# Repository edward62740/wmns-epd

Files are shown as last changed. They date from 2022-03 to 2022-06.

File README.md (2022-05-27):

# WMNS-EPD
Simple Wi-Fi/BLE enabled e-paper display. Designed for displaying real-time sensor data. Extention of [WMNS](https://github.com/edward62740/Wireless-Mesh-Network-System).</br></br>




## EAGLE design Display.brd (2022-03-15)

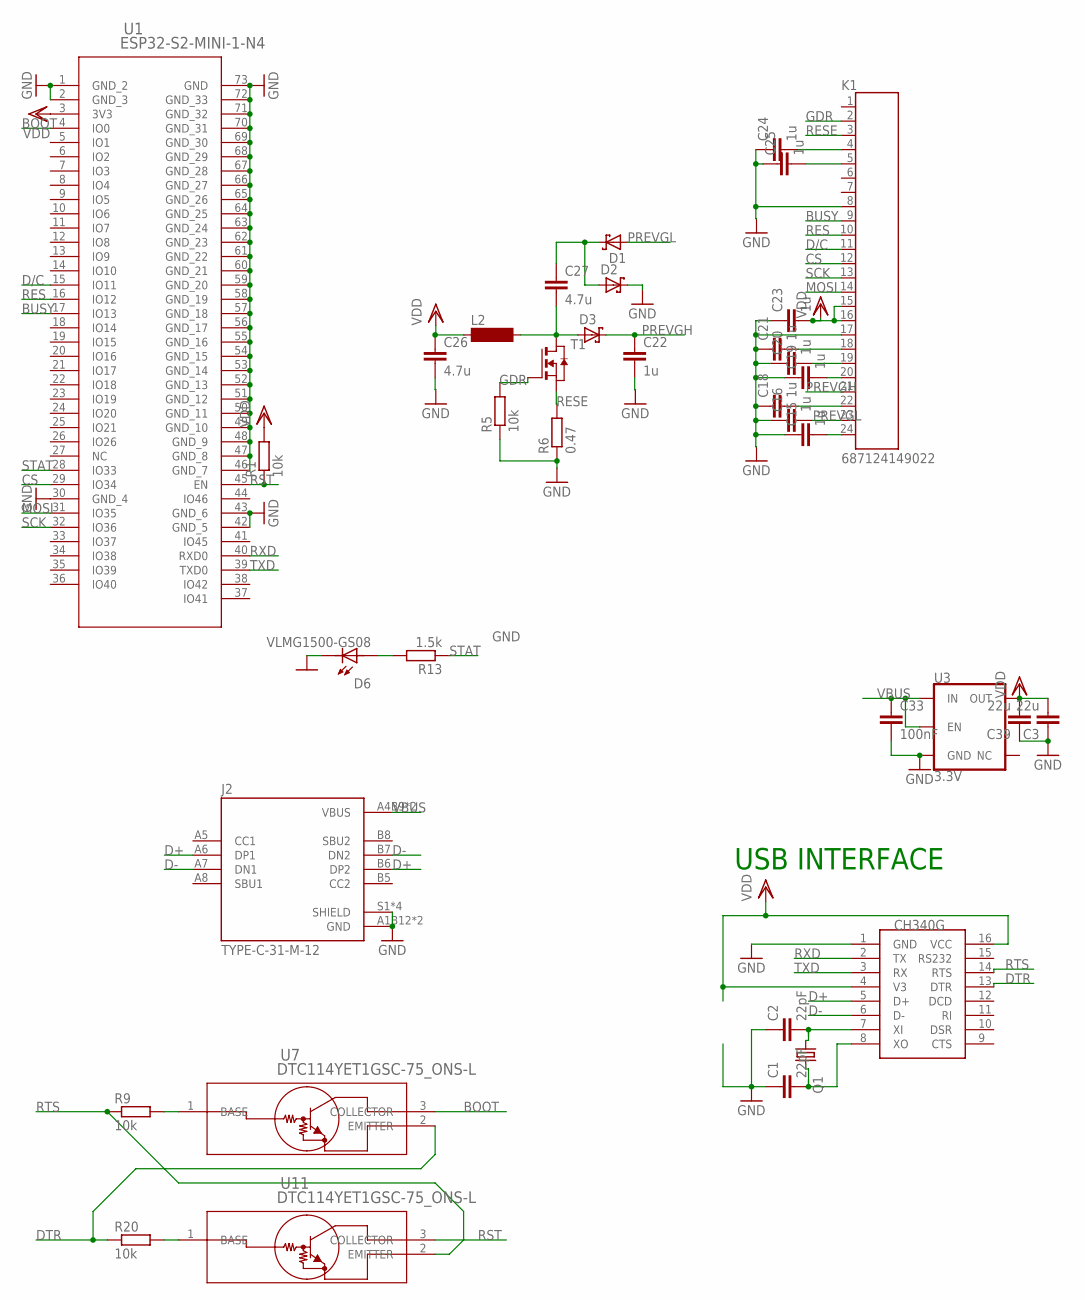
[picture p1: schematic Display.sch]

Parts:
C1, C2: 22pF; C0402
C3, C39: 22u; C0603R
C15, C16, C18, C19, C20, C21, C22, C23, C24, C25: 1u; C0402
C26, C27: 4.7u; C0402
C33: 100nF; C0402
D1, D2, D3: 1PS79SB30,115; SOD523
D6: VLMG1500-GS08; LEDC1005X35N
J2: TYPE-C-31-M-12; HRO_TYPE-C-31-M-12
K1: 687124149022
L2: SM-NE29
Q1: KX-7; 3.2X2.5_KX-7
R1, R5, R9, R20: 10k; R0402
R6: 0.47; R0402
R13: 1.5k; R0402
T1: NMOSSOT23; SOT-23
U1: ESP32-S2-MINI-1-N4; ESP32-S2-MINI-1-N4_EXP
U3: 3.3V; SOT23-5
U5: H; SOIC16
U7, U11: DTC114YET1GSC-75_ONS-L; SC-75_ONS-L

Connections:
BOOT: U1.4 (IO0), U7.3 (COLLECTOR)
BUSY: K1.9, U1.17 (IO13)
CS: K1.12, U1.29 (IO34)
D+: J2.A6 (DP1), J2.B6 (DP2), U5.5 (D+)
D-: J2.A7 (DN1), J2.B7 (DN2), U5.6 (D-)
D/C: K1.11, U1.15 (IO11)
DTR: R20.1, U5.13 (DTR), U7.2 (EMITTER)
GDR: K1.2, R5.2, T1.3 (G)
GND: C1.1, C2.1, C3.1, C15.1, C16.1, C18.1, C19.1, C20.1, C21.1, C22.2, C23.1, C24.1, C25.1, C26.2, C33.2, C39.1, D2.1 (K), D6.2, J2.A1B12 (GND), J2.B1A12 (GND), J2.S1 (SHIELD), J2.S2 (SHIELD), J2.S3 (SHIELD), J2.S4 (SHIELD), K1.8, K1.17, R5.1, R6.1, U1.1 (GND_2), U1.2 (GND_3), U1.30 (GND_4), U1.42 (GND_5), U1.43 (GND_6), U1.46 (GND_7), U1.47 (GND_8), U1.48 (GND_9), U1.49 (GND_10), U1.50 (GND_11), U1.51 (GND_12), U1.52 (GND_13), U1.53 (GND_14), U1.54 (GND_15), U1.55 (GND_16), U1.56 (GND_17), U1.57 (GND_18), U1.58 (GND_19), U1.59 (GND_20), U1.60 (GND_21), U1.61 (GND_22), U1.62 (GND_23), U1.63 (GND_24), U1.64 (GND_25), U1.65 (GND_26), U1.66 (GND_27), U1.67 (GND_28), U1.68 (GND_29), U1.69 (GND_30), U1.70 (GND_31), U1.71 (GND_32), U1.72 (GND_33), U1.73 (GND), U3.2 (GND), U5.1 (GND)
MOSI: K1.14, U1.31 (IO35)
unnamed: C1.2, Q1.3 (2), U5.8 (XO)
unnamed: C27.2, D3.2 (A), L2.2, T1.1 (D)
unnamed: C21.2, K1.18
unnamed: C2.2, Q1.1, U5.7 (XI)
unnamed: C18.2, K1.22
unnamed: C20.2, K1.19
unnamed: C19.2, K1.20
unnamed: C15.2, K1.24
unnamed: C24.2, K1.4
unnamed: C25.2, K1.5
unnamed: C27.1, D1.1 (K), D2.2 (A)
unnamed: D6.1, R13.2
unnamed: R20.2, U11.1 (BASE)
unnamed: R9.2, U7.1 (BASE)
PREVGH: C22.1, D3.1 (K), K1.21
PREVGL: C16.2, D1.2 (A), K1.23
RES: K1.10, U1.16 (IO12)
RESE: K1.3, R6.2, T1.2 (S)
RST: R1.1, U1.45 (EN), U11.3 (COLLECTOR)
RTS: R9.1, U5.14 (RTS), U11.2 (EMITTER)
RXD: U1.40 (RXD0), U5.2 (TX)
SCK: K1.13, U1.32 (IO36)
STAT: R13.1, U1.28 (IO33)
TXD: U1.39 (TXD0), U5.3 (RX)
VBUS: C33.1, J2.A4B9 (VBUS), J2.B4A9 (VBUS), U3.1 (IN), U3.3 (EN)
VDD: C3.2, C23.2, C26.1, C39.2, K1.15, K1.16, L2.1, R1.2, U1.3 (3V3), U3.5 (OUT), U5.4 (V3), U5.16 (VCC)

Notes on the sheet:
USB INTERFACE

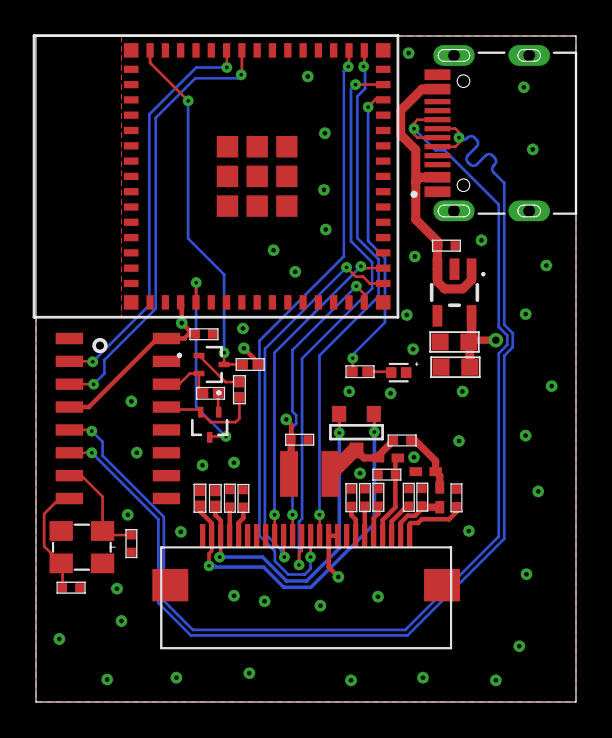
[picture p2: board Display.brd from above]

Board: 4 copper layers, 30.0 x 37.0 mm, 37 parts (0 on the bottom side), 36 nets.

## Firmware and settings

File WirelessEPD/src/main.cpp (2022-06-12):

#include <Arduino.h>
#include <GxEPD2_BW.h> // including both doesn't use more code or ram
#include <GxEPD2_3C.h> // including both doesn't use more code or ram
#include <Fonts/FreeMonoBold18pt7b.h>
#include <Fonts/FreeSansBold24pt7b.h>
#include <Fonts/FreeSansBold18pt7b.h>
#include <Fonts/FreeSansBold12pt7b.h>
#include <Fonts/FreeSansBold9pt7b.h>
#include <Fonts/FreeSans9pt7b.h>
#include <InfluxDbClient.h>
#include <InfluxDbCloud.h>

/* InfluxDB Connection Parameters */
#define WIFI_SSID ""
#define WIFI_PASSWORD ""
#define INFLUXDB_URL ""
// InfluxDB v2 server or cloud API authentication token (Use: InfluxDB UI -> Data -> Tokens -> <select token>)
#define INFLUXDB_TOKEN ""
// InfluxDB v2 organization id (Use: InfluxDB UI -> User -> About -> Common Ids )
#define INFLUXDB_ORG ""
// InfluxDB v2 bucket name (Use: InfluxDB UI ->  Data -> Buckets)
#define INFLUXDB_BUCKET ""
#define TZ_INFO ""
#include <esp_task_wdt.h>
InfluxDBClient client(INFLUXDB_URL, INFLUXDB_ORG, INFLUXDB_BUCKET, INFLUXDB_TOKEN, InfluxDbCloud2CACert);
unsigned long previousMillis = 0;
uint32_t co2_hist[25] = {0, 0, 0, 0, 0, 0, 0, 0, 0, 0, 0, 0, 0, 0, 0, 0, 0, 0, 0, 0, 0, 0, 0, 0, 0};
uint32_t co2_max = 0;
uint32_t co2_min = 0;
GxEPD2_3C<GxEPD2_154_Z90c, GxEPD2_154_Z90c::HEIGHT> display(GxEPD2_154_Z90c(/*CS=D8*/ SS, /*DC=D3*/ 11, /*RST=D4*/ 12, /*BUSY=D2*/ 13));
bool boot = true;
void setup()
{

    pinMode(33, OUTPUT);
    Serial.begin(115200);
    WiFi.mode(WIFI_STA);

    WiFi.begin(WIFI_SSID, WIFI_PASSWORD);
    while (WiFi.status() != WL_CONNECTED)
    {
        Serial.println(WiFi.status());
        delay(2500);
    }

    client.setHTTPOptions(HTTPOptions().httpReadTimeout(200));
    client.setHTTPOptions(HTTPOptions().connectionReuse(true));
    // Check server connection
    if (client.validateConnection())
    {
        Serial.print("Connected to InfluxDB: ");
        Serial.println(client.getServerUrl());
    }
    else
    {
        Serial.print("InfluxDB connection failed: ");
        Serial.println(client.getLastErrorMessage());
    }
    Serial.println("[INIT] IFDB CONNECTION OK");
}
void loop()
{
    esp_task_wdt_init(15, true);

    display.init();
    display.setRotation(1);
    for (uint8_t i = 0; i < 25; i++)
    {
        co2_hist[i] = 500;
        co2_max = 500;
    }

    while (1)
    {
        if (WiFi.status() != WL_CONNECTED)
        {
            WiFi.disconnect();
            WiFi.begin(WIFI_SSID, WIFI_PASSWORD);
            vTaskDelay(2000);
        }
        unsigned long currentMillis = millis();
        if ((currentMillis - previousMillis >= 300000) || boot)
        {
            display.fillScreen(GxEPD_BLACK);
            previousMillis = currentMillis;
            String query = "from(bucket: \"MESH\") |> range(start: -1h) |> filter(fn: (r) => r._measurement == \"CO2\") |> filter(fn: (r) => r.UID == \"22016\") |> filter(fn: (r) => r._field == \"CO2\") |> last()";
            FluxQueryResult result = client.query(query);
            uint32_t co2 = 1;
            while (result.next())
            {
                co2 = (uint32_t)result.getValueByName("_value").getDouble();
            }
            display.setFont(&FreeSansBold24pt7b);
            display.setTextColor(GxEPD_WHITE);
            display.setCursor(1, 38);
            display.print(co2);
            int16_t ulx, uly;
            uint16_t w, h;
            display.getTextBounds((String)co2, 1, 40, &ulx, &uly, &w, &h);
            display.setTextColor(GxEPD_WHITE);
            display.setFont(&FreeSansBold12pt7b);

            display.setTextSize(1);
            display.setCursor(ulx + w + 3, 40);
            display.print("PPM");
            display.setCursor(ulx + w + 3, 20);
            display.setTextColor(GxEPD_RED);
            display.print("CO2");
            display.setTextColor(GxEPD_WHITE);
            digitalWrite(33, !digitalRead(33));
            co2_max = 1;
            co2_min = 9999;
            for (uint8_t i = 1; i < 25; i++)
            {

                memmove(&co2_hist[i - 1], &co2_hist[i], sizeof(uint32_t));
                Serial.print(co2_hist[i - 1]);
                Serial.print(" ");
                if (co2_hist[i] > co2_max)
                    co2_max = co2_hist[i];
                if ((co2_hist[i] < co2_min) && co2_hist[i] != 0)
                    co2_min = co2_hist[i];
            }
            if ((uint32_t)co2 > co2_max)
                co2_max = (uint32_t)co2;
            if (((uint32_t)co2 < co2_min) && (uint32_t)co2 != 0)
                co2_min = (uint32_t)co2;
            co2_hist[24] = (uint32_t)co2;
            display.getTextBounds("CO2", ulx + w + 5, 20, &ulx, &uly, &w, &h);
            display.setCursor(ulx + w + 2, 18);
            display.setFont(&FreeSansBold9pt7b);
            display.print(co2_max);
            display.setCursor(ulx + w + 2, 38);
            display.setFont(&FreeSansBold9pt7b);
            display.print(co2_min);
            for (uint8_t i = 0; i < 24; i++)
            {
                float hy = (50.00 / ((float)co2_max - (float)co2_min)) * ((float)co2_hist[i] - (float)co2_min);
                float ly = 0;
                float l2y = 0;
                float l3y = 0;
                float l4y = 0;
                float diff = 0;
                if (i != 24)
                {
                    diff = (float)co2_hist[i + 1] - (float)co2_hist[i];
                    ly = (50.00 / ((float)co2_max - (float)co2_min)) * (((float)co2_hist[i] - (float)co2_min) + (diff * 0.15));
                    l2y = (50.00 / ((float)co2_max - (float)co2_min)) * (((float)co2_hist[i] - (float)co2_min) + (diff * 0.50));
                    l3y = (50.00 / ((float)co2_max - (float)co2_min)) * (((float)co2_hist[i] - (float)co2_min) + (diff * 0.85));
                    l4y = (50.00 / ((float)co2_max - (float)co2_min)) * (((float)co2_hist[i] - (float)co2_min) + (diff));

                    Serial.println(" ");
                    Serial.print(ly);
                    Serial.print(" ");
                    Serial.print(l2y);
                    Serial.print(" ");
                    Serial.print(l3y);
                    Serial.print(" ");
                    Serial.print(l4y);
                    Serial.print(" ");
                    Serial.print(diff);

                    display.drawLine(0 + i * 8, 100 - hy, 2 + i * 8, 100 - ly, GxEPD_WHITE);
                    display.drawLine(2 + i * 8, 100 - ly, 4 + i * 8, 100 - l2y, GxEPD_WHITE);
                    display.drawLine(4 + i * 8, 100 - l2y, 6 + i * 8, 100 - l3y, GxEPD_WHITE);
                    display.drawLine(6 + i * 8, 100 - l3y, 8 + i * 8, 100 - l4y, GxEPD_WHITE);
                    display.drawLine(0 + i * 8, 100 - hy - 1, 2 + i * 8, 100 - ly - 1, GxEPD_WHITE);
                    display.drawLine(2 + i * 8, 100 - ly - 1, 4 + i * 8, 100 - l2y - 1, GxEPD_WHITE);
                    display.drawLine(4 + i * 8, 100 - l2y - 1, 6 + i * 8, 100 - l3y - 1, GxEPD_WHITE);
                    display.drawLine(6 + i * 8, 100 - l3y - 1, 8 + i * 8, 100 - l4y - 1, GxEPD_WHITE);
                    display.drawLine(0 + i * 8, 100 - hy - 2, 2 + i * 8, 100 - ly - 2, GxEPD_WHITE);
                    display.drawLine(2 + i * 8, 100 - ly - 2, 4 + i * 8, 100 - l2y - 2, GxEPD_WHITE);
                    display.drawLine(4 + i * 8, 100 - l2y - 2, 6 + i * 8, 100 - l3y - 2, GxEPD_WHITE);
                    display.drawLine(6 + i * 8, 100 - l3y - 2, 8 + i * 8, 100 - l4y - 2, GxEPD_WHITE);

                    display.drawFastVLine(2 + i * 8, 105 - ly, ly, GxEPD_WHITE);
                    display.drawFastVLine(4 + i * 8, 105 - l2y, l2y, GxEPD_WHITE);
                    display.drawFastVLine(6 + i * 8, 105 - l3y, l3y, GxEPD_WHITE);
                    display.drawFastVLine(8 + i * 8, 105 - l4y, l4y, GxEPD_WHITE);
                    display.fillRect(0, 102, 200, 5, GxEPD_BLACK);
                    digitalWrite(33, !digitalRead(33));
                }
            }
            if (boot)
            {
                display.setTextColor(GxEPD_LIGHTGREY);
                display.setFont(&FreeSansBold9pt7b);
                display.setTextSize(1);
                display.setCursor(20, 70);
                display.print("Graph loading...");
                boot = false;
            }
            display.fillCircle(0 + 25 * 8 - 5, 100 - (50.00 / ((float)co2_max - (float)co2_min)) * ((float)co2_hist[24] - (float)co2_min), 3, GxEPD_WHITE);
            String query1 = "from(bucket: \"MESH\") |> range(start: -15m) |> filter(fn: (r) => r._measurement == \"Environment\") |> filter(fn: (r) => r.UID == \"4102\") |> filter(fn: (r) => r._field == \"Temperature\") |> last()";
            FluxQueryResult result1 = client.query(query1);
            double temp = 0;
            while (result1.next())
            {
                temp = (double)result1.getValueByName("_value").getDouble();
            }
            display.setFont(&FreeSansBold18pt7b);
            display.setTextColor(GxEPD_WHITE);
            display.setCursor(2, 130);
            display.print(temp);
            display.getTextBounds((String)temp, 2, 130, &ulx, &uly, &w, &h);
            display.setTextColor(GxEPD_WHITE);
            display.setFont(&FreeSansBold9pt7b);
            display.setTextSize(1);
            display.setCursor(ulx + w + 5, 132);
            display.print("deg C");
            display.setCursor(ulx + w + 5, 118);
            display.setTextColor(GxEPD_RED);
            display.print("TEMP");
            String query2 = "from(bucket: \"MESH\") |> range(start: -15m) |> filter(fn: (r) => r._measurement == \"Environment\") |> filter(fn: (r) => r.UID == \"4102\") |> filter(fn: (r) => r._field == \"Humidity\") |> last()";
            FluxQueryResult result2 = client.query(query2);
            double humi = 0;
            digitalWrite(33, !digitalRead(33));
            while (result2.next())
            {
                humi = (double)result2.getValueByName("_value").getDouble();
            }
            display.setFont(&FreeSansBold18pt7b);
            display.setTextColor(GxEPD_WHITE);
            display.setCursor(2, 160);
            display.print(humi);
            display.getTextBounds((String)humi, 2, 160, &ulx, &uly, &w, &h);
            display.setTextColor(GxEPD_WHITE);
            display.setFont(&FreeSansBold9pt7b);
            display.setTextSize(1);
            display.setCursor(ulx + w + 5, 162);
            display.print("%");
            display.setCursor(ulx + w + 5, 148);
            display.setTextColor(GxEPD_RED);
            display.print("HUMIDITY");
            String query3 = "from(bucket: \"MESH\") |> range(start: -15m) |> filter(fn: (r) => r._measurement == \"Environment\") |> filter(fn: (r) => r.UID == \"4102\") |> filter(fn: (r) => r._field == \"Pressure\") |> last()";
            FluxQueryResult result3 = client.query(query3);
            uint16_t pres = 0;
            digitalWrite(33, !digitalRead(33));
            while (result3.next())
            {
                pres = (uint16_t)result3.getValueByName("_value").getDouble();
            }
            display.setFont(&FreeSansBold18pt7b);
            display.setTextColor(GxEPD_WHITE);
            display.setCursor(2, 191);
            display.print((uint16_t)pres);
            display.getTextBounds((String)pres, 2, 160, &ulx, &uly, &w, &h);
            display.setTextColor(GxEPD_WHITE);
            display.setFont(&FreeSansBold9pt7b);
            display.setTextSize(1);
            display.setCursor(ulx + w + 5, 192);
            display.print("hPa");
            display.setCursor(ulx + w + 5, 178);
            display.setTextColor(GxEPD_RED);
            display.print("PRESSURE");

            digitalWrite(33, !digitalRead(33));
            display.display();
            digitalWrite(33, !digitalRead(33));
            display.powerOff();
        }
        // yield();
        String keepalive = "from(bucket: \"MESH\") |> range(start: -0m) |> filter(fn: (r) => r._measurement == \"NULL\") |> filter(fn: (r) => r.UID == \"NULL\") |> filter(fn: (r) => r._field == \"NULL\") |> last()";
        FluxQueryResult l = client.query(keepalive);
        delay(5000);
        digitalWrite(33, !digitalRead(33));
        
    }
}

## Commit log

2022-03-15 Added PCB
    [Display.brd, Display.sch]
2022-06-12 Added display power down to prevent screen fading
    [main.cpp]
2022-06-24 Fixed power off issue in GxEPD2_154_Z90c.cpp
    This issue caused fading display over time.
    Changed value of register 0x22 from 0xc3 (invalid) -> 0x03 per datasheet (https://v4.cecdn.yun300.cn/100001_1909185148/GDEH0154Z90-0111.pdf)

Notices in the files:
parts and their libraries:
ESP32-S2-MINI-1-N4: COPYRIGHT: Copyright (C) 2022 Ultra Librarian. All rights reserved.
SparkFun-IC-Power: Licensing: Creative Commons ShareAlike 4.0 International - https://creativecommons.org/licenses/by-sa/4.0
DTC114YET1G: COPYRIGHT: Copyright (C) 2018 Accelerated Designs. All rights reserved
